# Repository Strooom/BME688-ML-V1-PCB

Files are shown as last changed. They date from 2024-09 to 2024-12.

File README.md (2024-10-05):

# BME688 Machine Learning PCB



KiCAD design files for the BME688 Machine Learning PCB.

## Front render
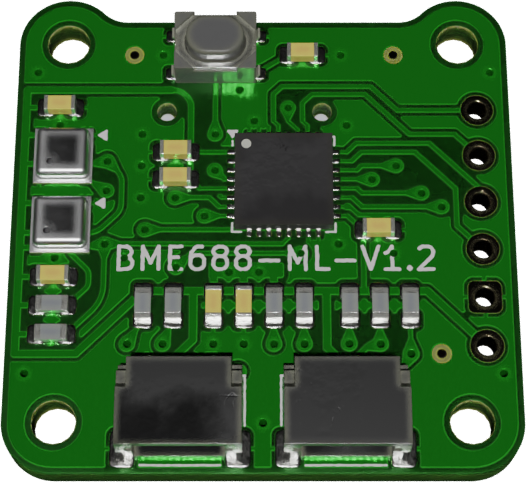
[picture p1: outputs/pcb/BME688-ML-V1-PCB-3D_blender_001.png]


## Back render
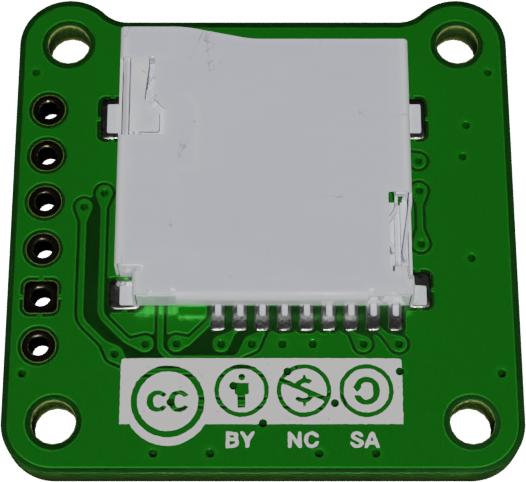
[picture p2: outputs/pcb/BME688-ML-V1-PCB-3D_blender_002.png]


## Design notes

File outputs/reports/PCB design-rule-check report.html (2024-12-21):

Logo

| DRC report for BME688-ML-V1-PCB
| PCB: BME688-ML-V1-PCB Revision: None Date: 2024-12-21T13:22:17+0000 KiCad Version: 8.0.6 | Errors: 0 Warnings: 0 Total: 0

Generated by KiBot (https://github.com/INTI-CMNB/KiBot/) v1.8.2

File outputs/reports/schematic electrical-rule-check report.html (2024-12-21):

Logo

| ERC report for BME688-ML-V1-PCB
| Schematic: BME688-ML-V1-PCB Revision: V1 Date: 2024-12-21T13:22:16+0000 KiCad Version: 8.0.6 | Errors: 0 Warnings: 2 Total: 2

Sheet / (BME688-ML-V1-PCB.kicad_sch)

Type | Description | Details
lib_symbol_issues | Symbol 'Qwiic connector' has been modified in library '1projectLibrary' | @(0.7493 mm, 1.4732 mm): Symbol CONN1 [Qwiic connector]
lib_symbol_issues | Symbol 'Qwiic connector' has been modified in library '1projectLibrary' | @(1.0033 mm, 1.4732 mm): Symbol CONN2 [Qwiic connector]

Generated by KiBot (https://github.com/INTI-CMNB/KiBot/) v1.8.2

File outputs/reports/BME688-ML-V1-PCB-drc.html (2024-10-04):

Logo

| DRC report for BME688-ML-V1-PCB
| PCB: BME688-ML-V1-PCB Revision: Date: 2024-10-04T11:17:32+0000 KiCad Version: 8.0.4 | Errors: 0 Warnings: 0 Total: 0

Generated by KiBot (https://github.com/INTI-CMNB/KiBot/) v1.8.1

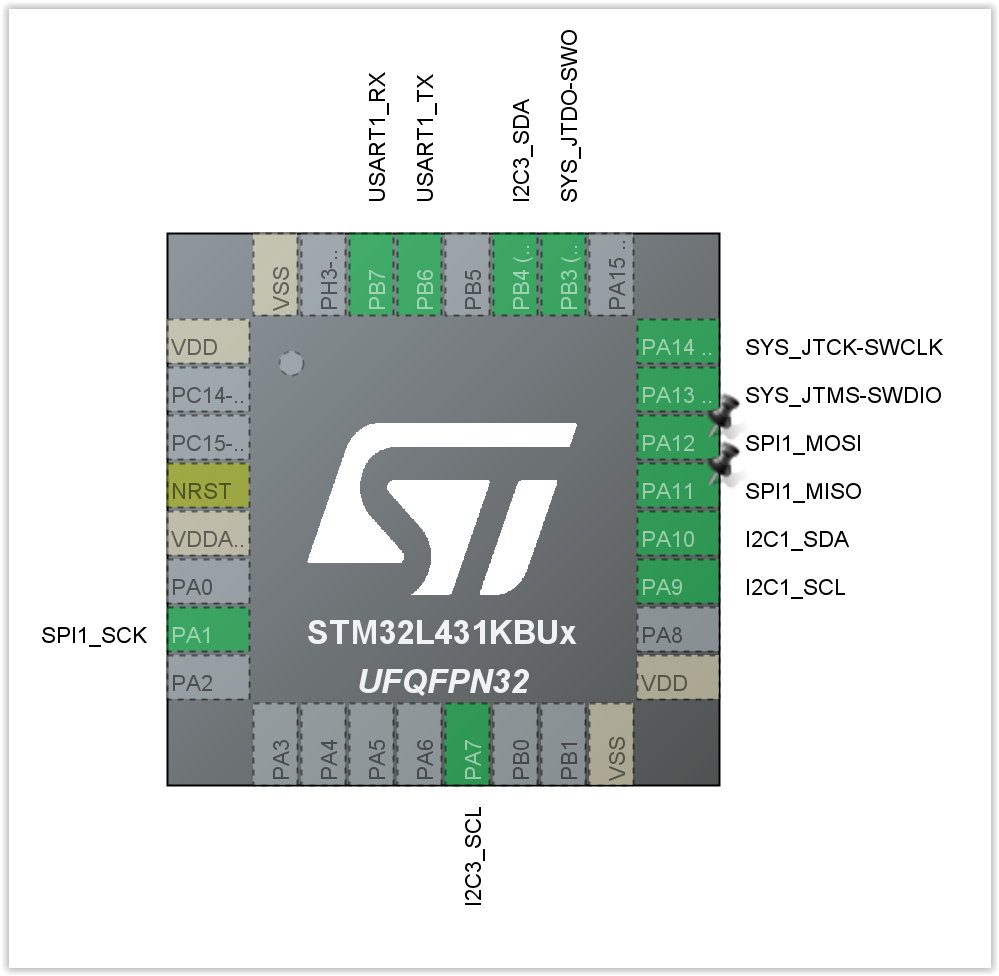
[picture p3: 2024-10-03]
inputs/other/Pinout STM32.PNG

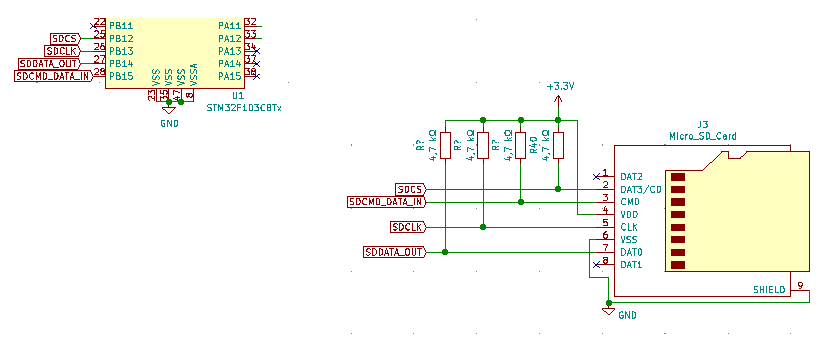
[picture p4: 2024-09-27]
inputs/other/kwdvX.png

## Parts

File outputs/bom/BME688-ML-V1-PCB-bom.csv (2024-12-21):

Row | Description | Part | References | Value | Footprint | Quantity Per PCB | Status | Datasheet | GPN | manufacturerName | manufacturerPartNumber | digikeyPartNumber | mouserPartNumber | octopartUrl | MPN | manufacturer | supplier1Name | supplier1PartNumber | supplier1PartURL | supplier2Name | supplier2PartNumber | supplier2PartURL | remark
1 | 4u7 | C | C4 C5 | C0603C475K8PAC7411 | C_0603_nominal | 2 |  | https://www.mouser.be/datasheet/2/447/KEM_C1006_X5R_SMD-3316465.pdf | GPC0603475 | Yageo - Kemet | C0603C475K8PAC7411 | 399-C0603C475K8PAC7411CT-ND | 80-C0603C475K8PACLR | https://octopart.com/c0603c475k8pac7411-kemet-75146718?r= | C0603C475K8PAC7411
2 | 100nF | C | C1 C2 C3 C6 C7 C8 | KGM15AR71C104KT | C_0603_nominal | 6 |  | https://www.mouser.be/datasheet/2/40/KGM_X7R-3223212.pdf | GPC0603104 | KYOCERA AVX | KGM15AR71C104KT | 478-KGM15AR71C104KTCT-ND | 581-KGM15AR71C104KT | https://octopart.com/kgm15ar71c104kt-avx-136559929?r=sp | KGM15AR71C104KT
3 | micro-SD card slot | microSdCard | CONN3 | MSD-1-A | MSD-1-A | 1 |  | https://www.mouser.be/datasheet/2/670/msd_1_a-3367597.pdf |  | CUI Devices | MSD-1-A |  | 179-MSD-1-A | https://octopart.com/msd-1-a-same+sky-145369555?r=sp | MSD-1-A
4 | Qwiic | Qwiic connector | CONN1 CONN2 | SM04B-SRSS-TB | JST_SH_SM04B-SRSS-TB_1x04-1MP_P1.00mm_Horizontal | 2 |  | https://www.mouser.be/datasheet/2/813/eSH-2487316.pdf |  | Sparkfun - JST | SM04B-SRSS-TB(LF)(DN)(P) |  | 306-SM04BSRSSTBLFDNP | https://octopart.com/sm04b-srss-tb%28lf%29%28dn%29%28p%29-jst-154671066?r=sp | SM04B-SRSS-TB
5 | Debug-SWD | Conn_01x06_Socket | CONN5 | notApplicable | DebugConnector_1x06_P2.54mm | 1 |  | notApplicable |  | notApplicable | notApplicable | notApplicable | notApplicable | notApplicable
6 | 4K7 | R | R1 R2 R3 R4 R5 R6 R7 R8 R9 | CR0603-FX-4701ELF | R_0603_nominal | 9 |  | https://www.mouser.be/datasheet/2/54/cr-1858361.pdf | GPR06034K7 | Bourns | CR0603-FX-4701ELF | CR0603-FX-4701ELFCT-ND | 652-CR0603FX-4701ELF | https://octopart.com/cr0603-fx-4701elf-bourns-3867100?r=sp | CR0603-FX-4701ELF
7 | Application buttonswitch | Switch_434133025816 | SW1 | 434133025816 | Wurth-434133025816 | 1 |  | https://www.we-online.com/components/products/datasheet/434133025816.pdf |  | Wurth Electronics | 434133025816 | 732-13663-1-ND | 710-434133025816 | https://octopart.com/434133025816-wurth+elektronik-99472342?r=sp | 434133025816
8 | Air Quality Sensors MEMS gas, humidity, pressure and temperature sensor | BME688 | U2 U3 | BME688 | BME688 | 2 |  | https://ae-bst.resource.bosch.com/media/_tech/media/datasheets/BST-BME680-DS001.pdf |  | Bosch Sensortec | BME688 | 828-BME688CT-ND | 262-BME688 | https://octopart.com/bme688-bosch+tools-116090840?r=sp | BME688 | Bosch Sensortec | Mouser | 262-BME680 | https://www.mouser.be/ProductDetail/Bosch-Sensortec/BME680?qs=v271MhAjFHjo0yA%2FC4OnDQ%3D%3D | Digi-Key | 828-1077-1-ND | https://www.digikey.be/nl/products/detail/bosch-sensortec/BME680/7401317
9 | STMicroelectronics Arm Cortex-M4 MCU, 128-256KB flash, 64KB RAM, 80 MHz, 1.71-3.6V, 26 GPIO, UFQFPN32 | STM32L431K | U1 | STM32L431KBU6TR | QFN-32-1EP_5x5mm_P0.5mm_EP3.45x3.45mm | 1 |  | https://www.st.com/resource/en/datasheet/stm32l431kb.pdf |  | ST | STM32L431KBU6TR | 497-18831-1-ND | 511-STM32L431KBU6TR | https://octopart.com/stm32l431kbu6tr-stmicroelectronics-89206856?r=sp | STM32L431KBU6TR
Project info:
Schematic: | BME688-ML-V1-PCB
Variant: | default
Revision: | V1
Date: | 2024-09-18
KiCad Version: | 8.0.6+1
Statistics:
Component Groups: | 9
Component Count: | 25
Fitted Components: | 25
Number of PCBs: | 1
Total Components: | 25

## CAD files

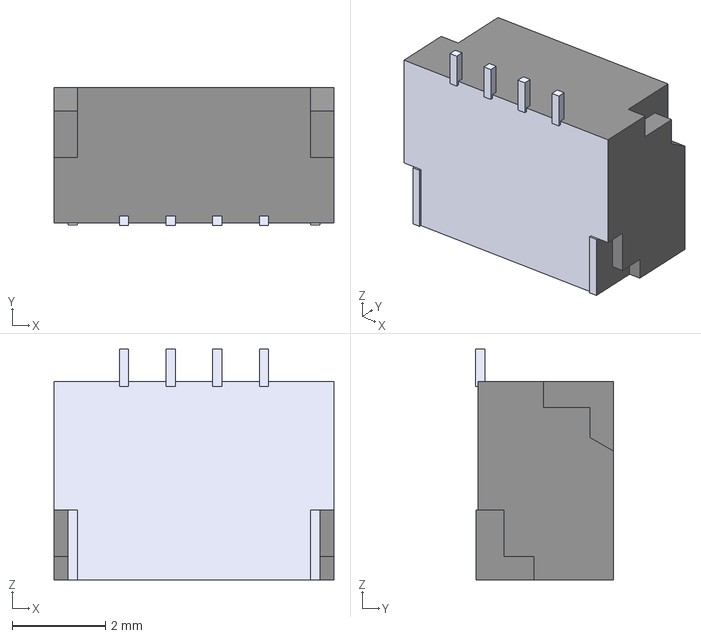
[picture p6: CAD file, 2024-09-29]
inputs/3dmodels/SPARKFUN_QWIIC_RIGHT_ANGLE.step
6.00 x 2.96 x 4.95 mm

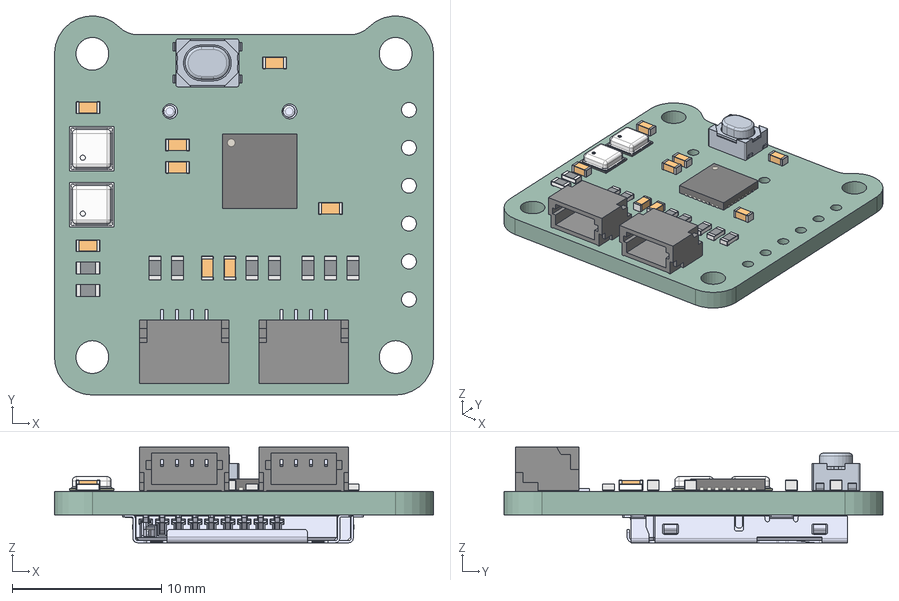
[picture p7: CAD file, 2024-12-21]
outputs/pcb/BME688-ML-V1-PCB-3D.step
25.4 x 25.4 x 6.40 mm
SPARKFUN_QWIIC_RIGHT_ANGLE_X x 2
QFN-32-1EP_5x5mm_Pitch0.5mm
Assem1
BME680 x 2
CUI_DEVICES_MSD-1-A
kibot_do8knjwf_PCB

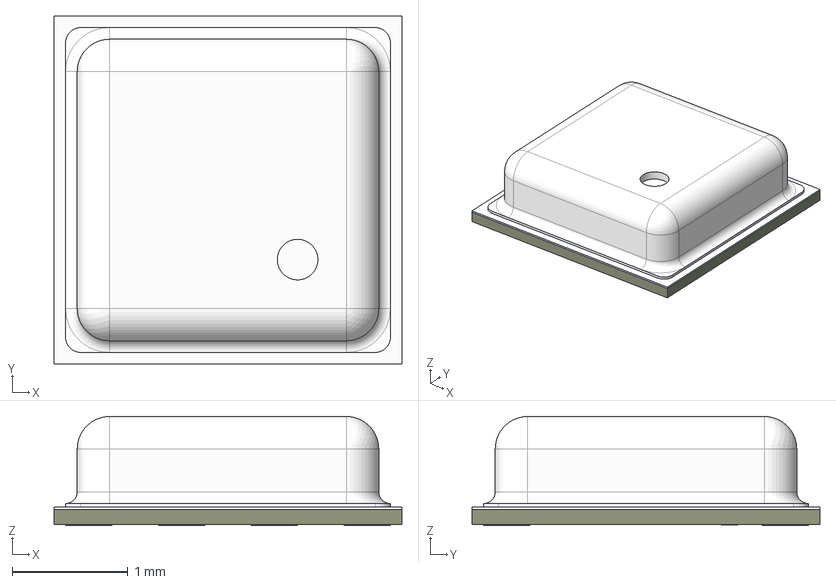
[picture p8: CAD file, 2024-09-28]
inputs/3dmodels/BME688.step
3.00 x 3.00 x 0.94 mm
pads
pcb
lid

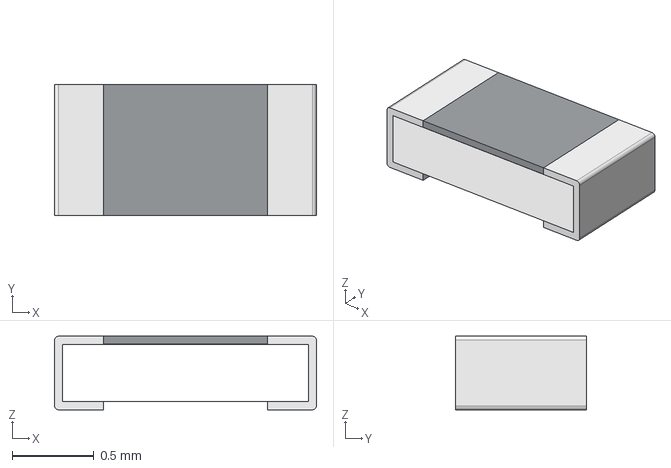
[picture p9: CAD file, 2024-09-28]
inputs/3dmodels/R0603.step
1.60 x 0.8 x 0.45 mm

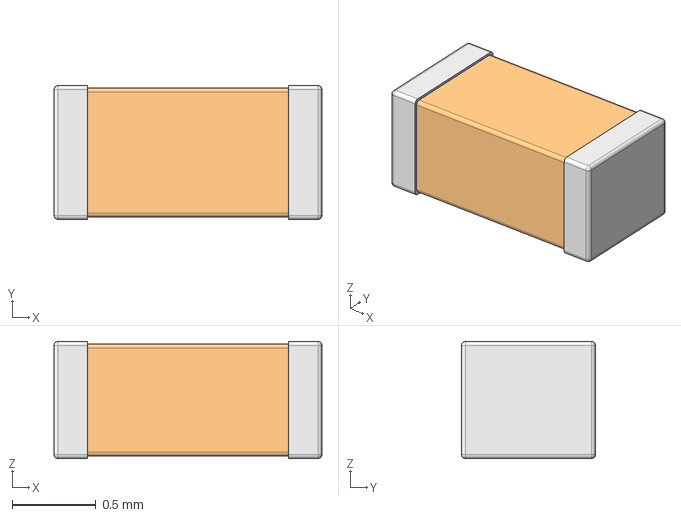
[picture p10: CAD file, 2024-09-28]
inputs/3dmodels/C0603.step
1.60 x 0.8 x 0.7 mm

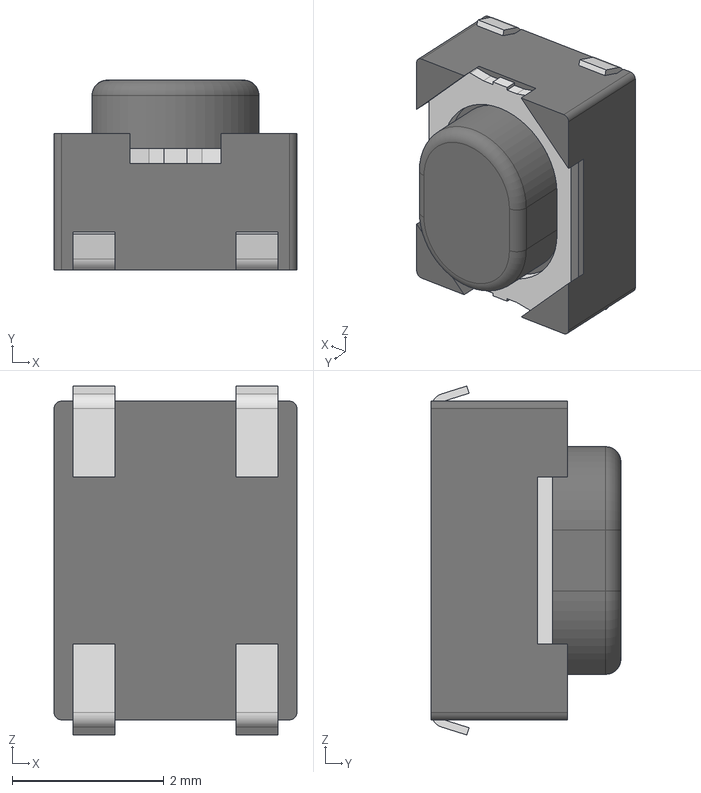
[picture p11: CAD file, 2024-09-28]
inputs/3dmodels/4341x30258x6.stp
3.20 x 2.50 x 4.60 mm
Frame
Cover
Stem
Terminal x 4

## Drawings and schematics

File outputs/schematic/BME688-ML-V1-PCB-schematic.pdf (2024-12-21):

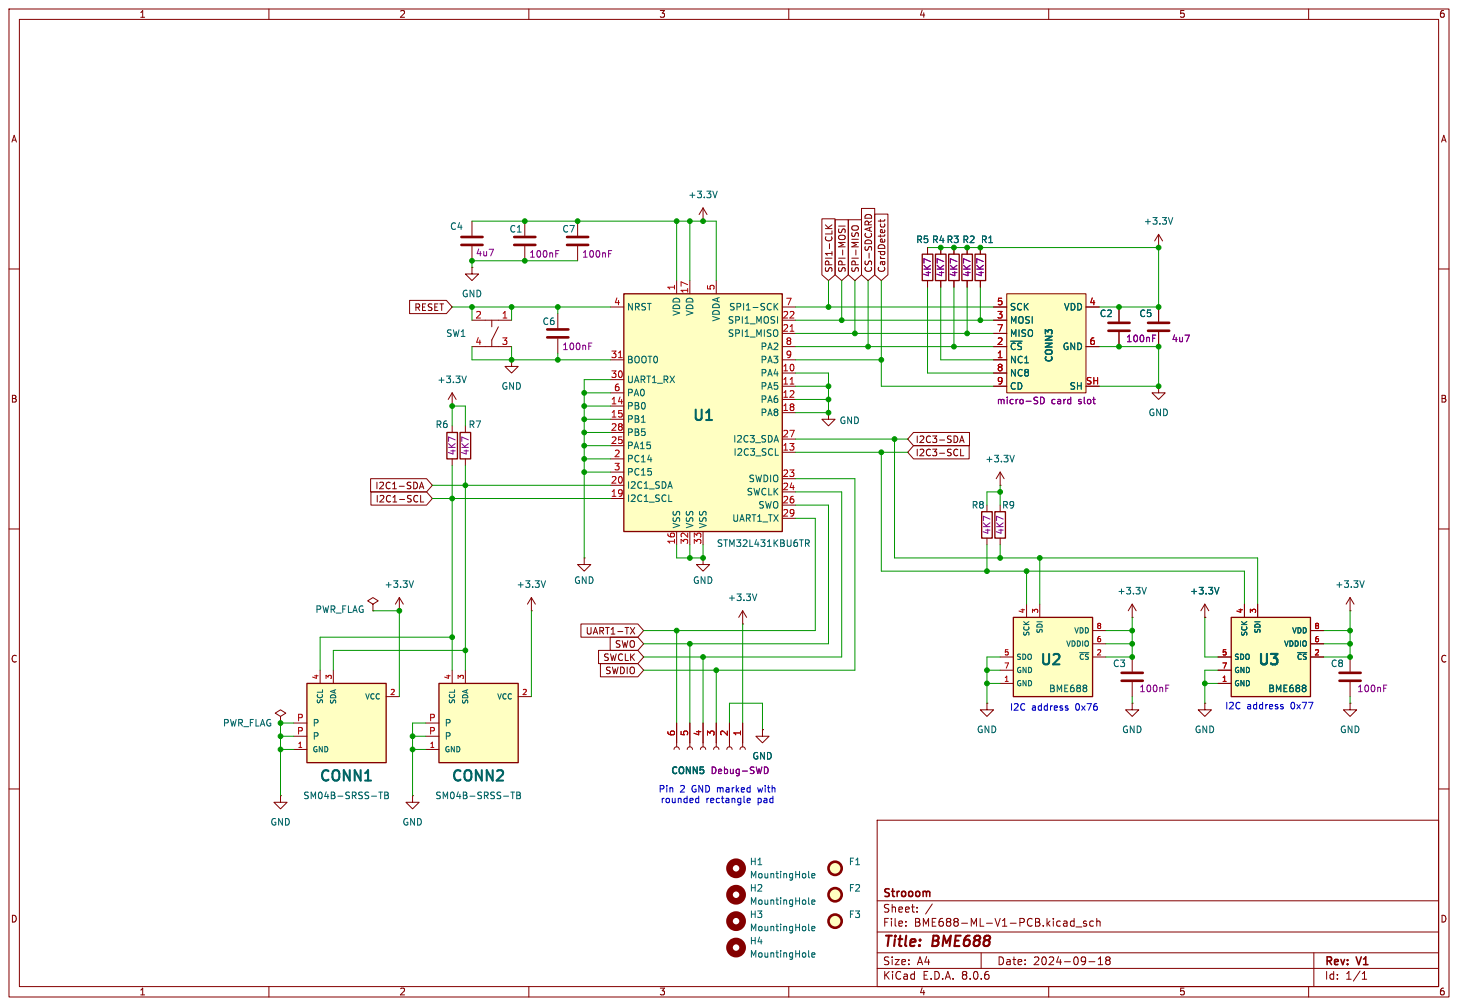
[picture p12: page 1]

4 SDO 5 VDDIO 6 GND 7 VDD 8 CONN3 micro-SD card slot NC1 1 ~{CS} 2 MOSI 3 VDD 4 SCK 5 GND 6 MISO 7 NC8 8 CD 9 SH SH

4 SDO 5 VDDIO 6 GND 7 VDD 8 U2

4 SDO 5 VDDIO 6 GND 7 VDD 8 U3

I2C address 0x77 Pin 2 GND marked with

File: BME688-ML-V1-PCB.kicad_sch Sheet: / Strooom

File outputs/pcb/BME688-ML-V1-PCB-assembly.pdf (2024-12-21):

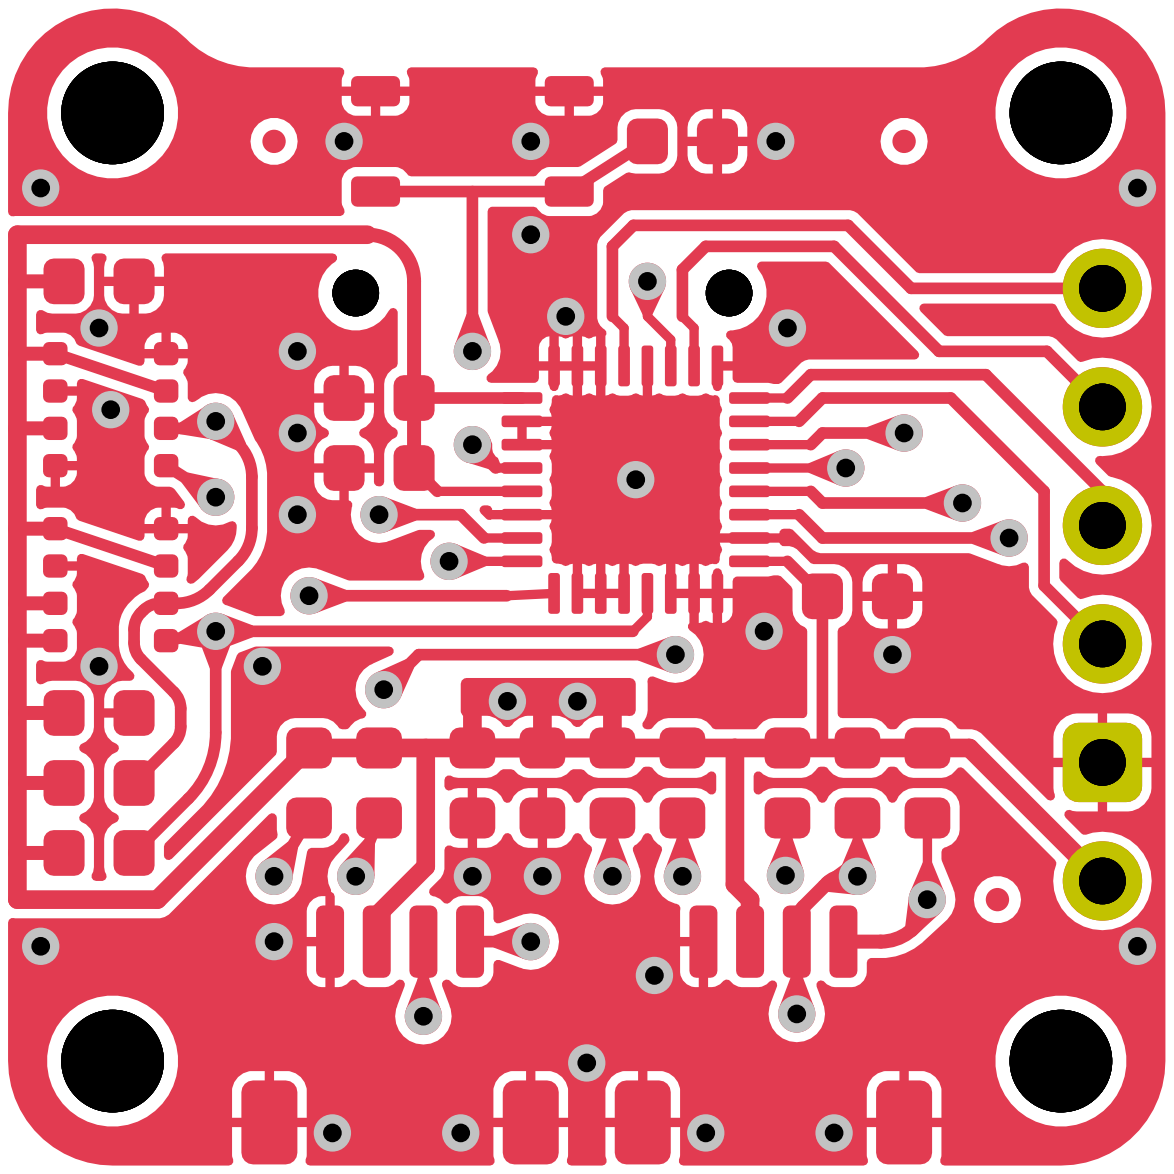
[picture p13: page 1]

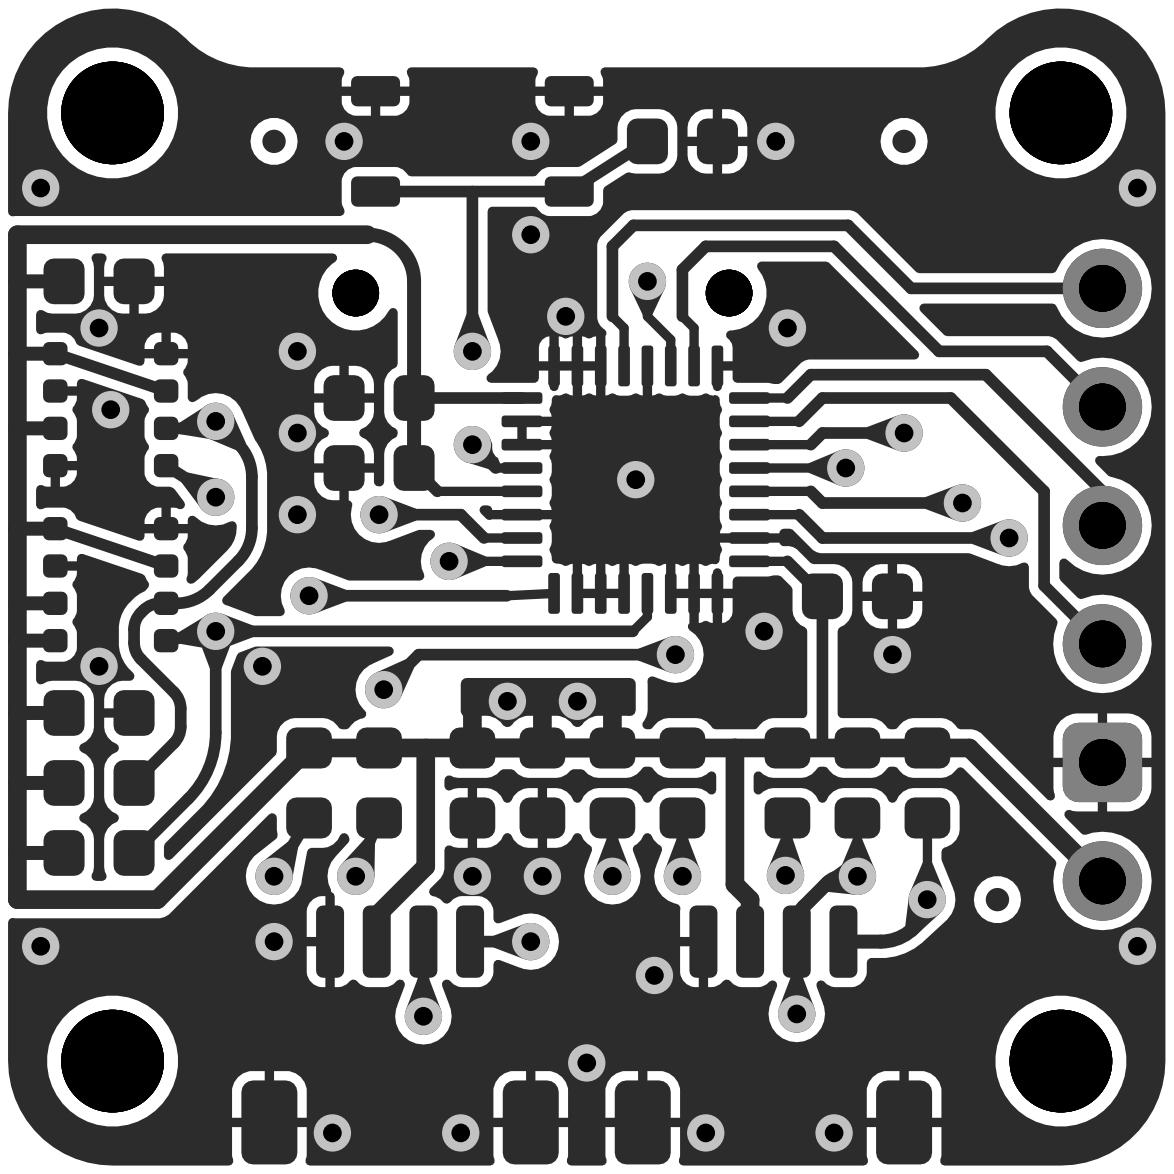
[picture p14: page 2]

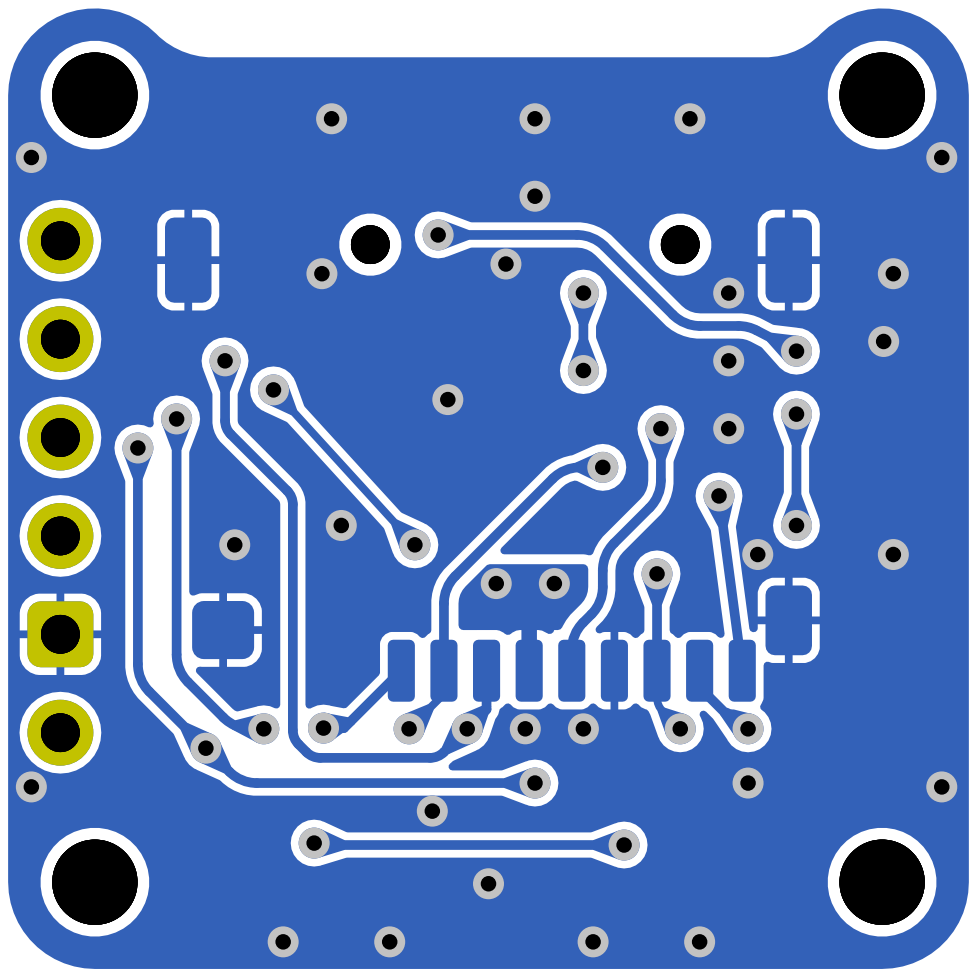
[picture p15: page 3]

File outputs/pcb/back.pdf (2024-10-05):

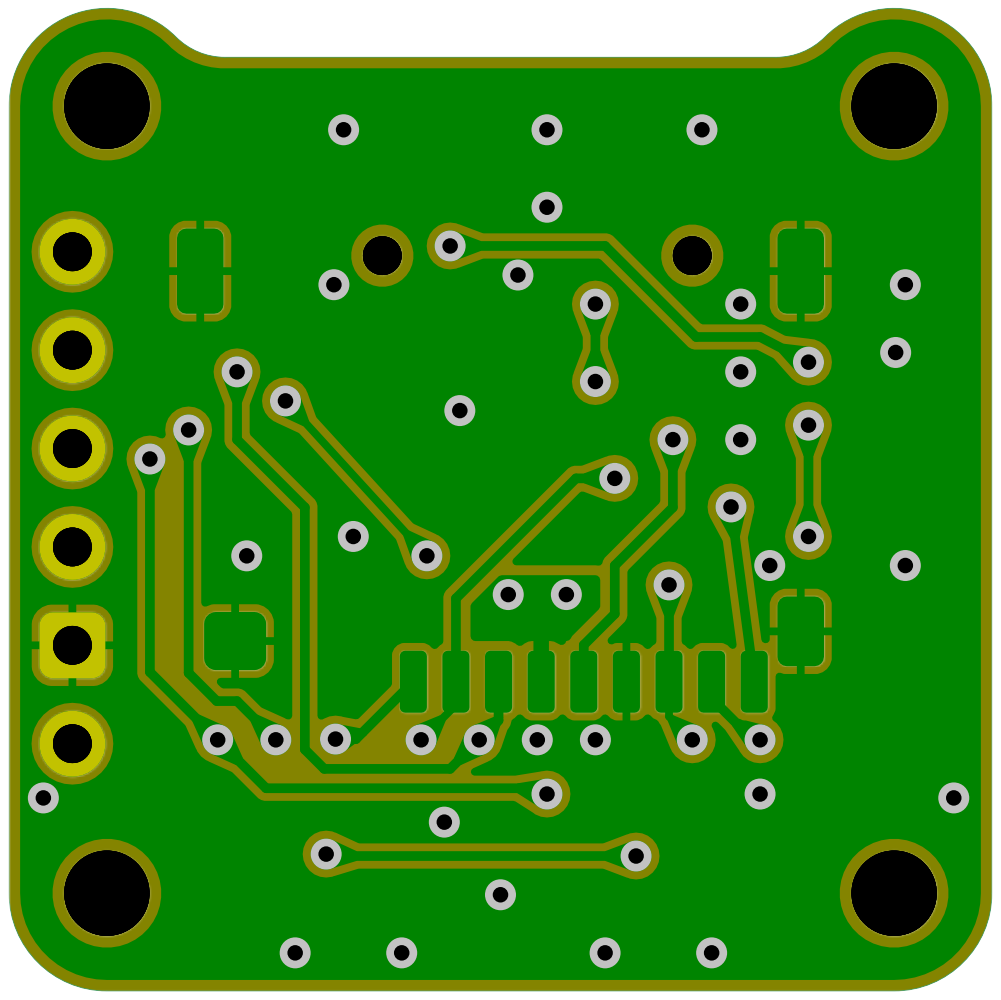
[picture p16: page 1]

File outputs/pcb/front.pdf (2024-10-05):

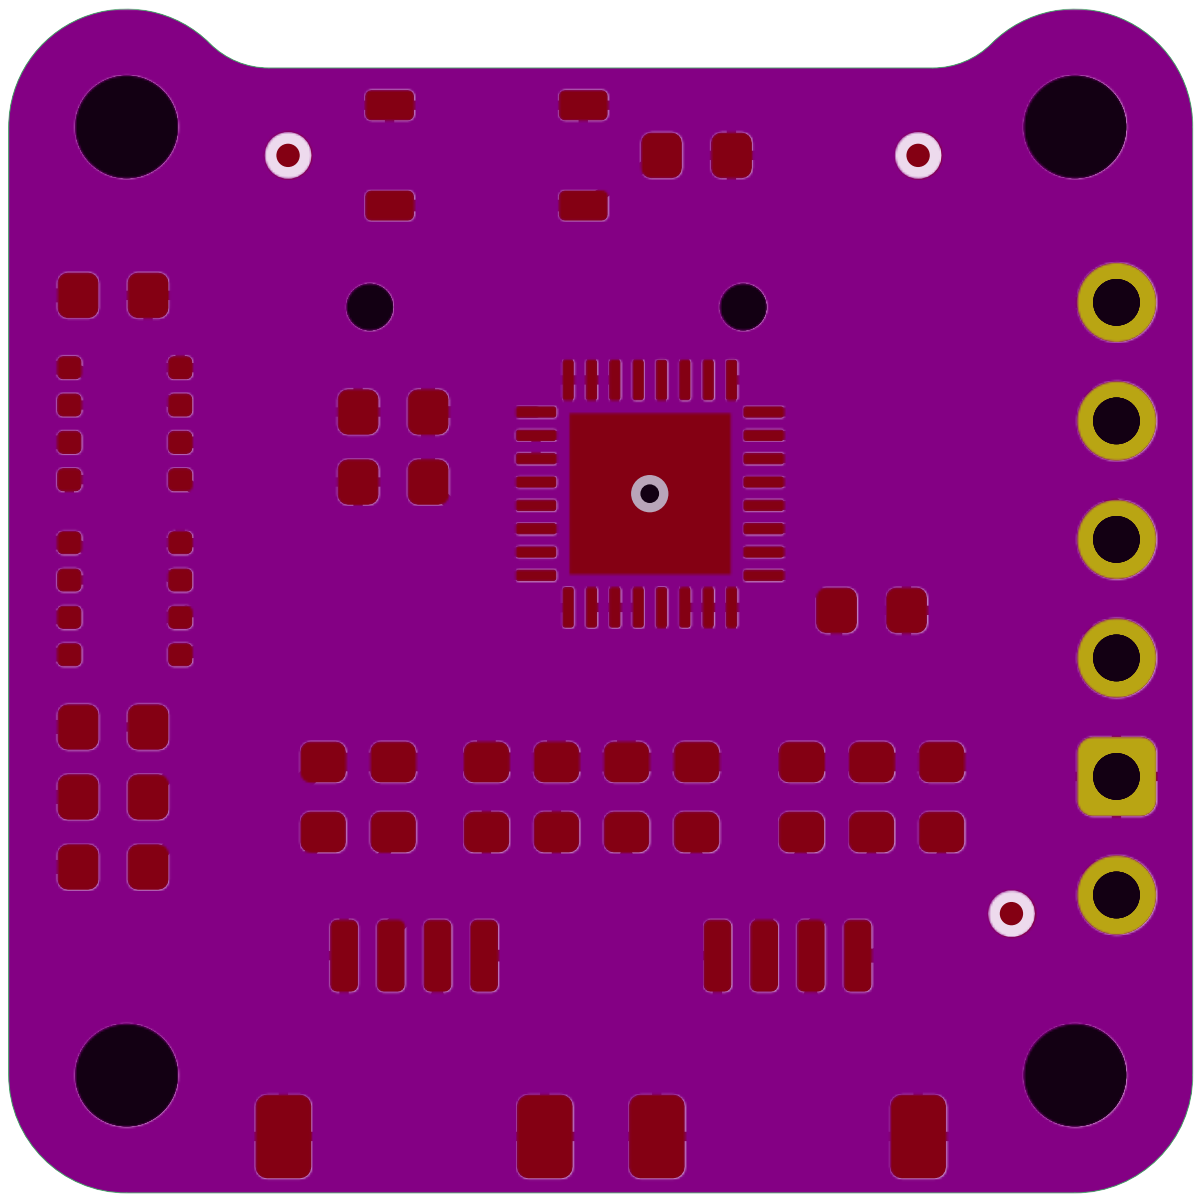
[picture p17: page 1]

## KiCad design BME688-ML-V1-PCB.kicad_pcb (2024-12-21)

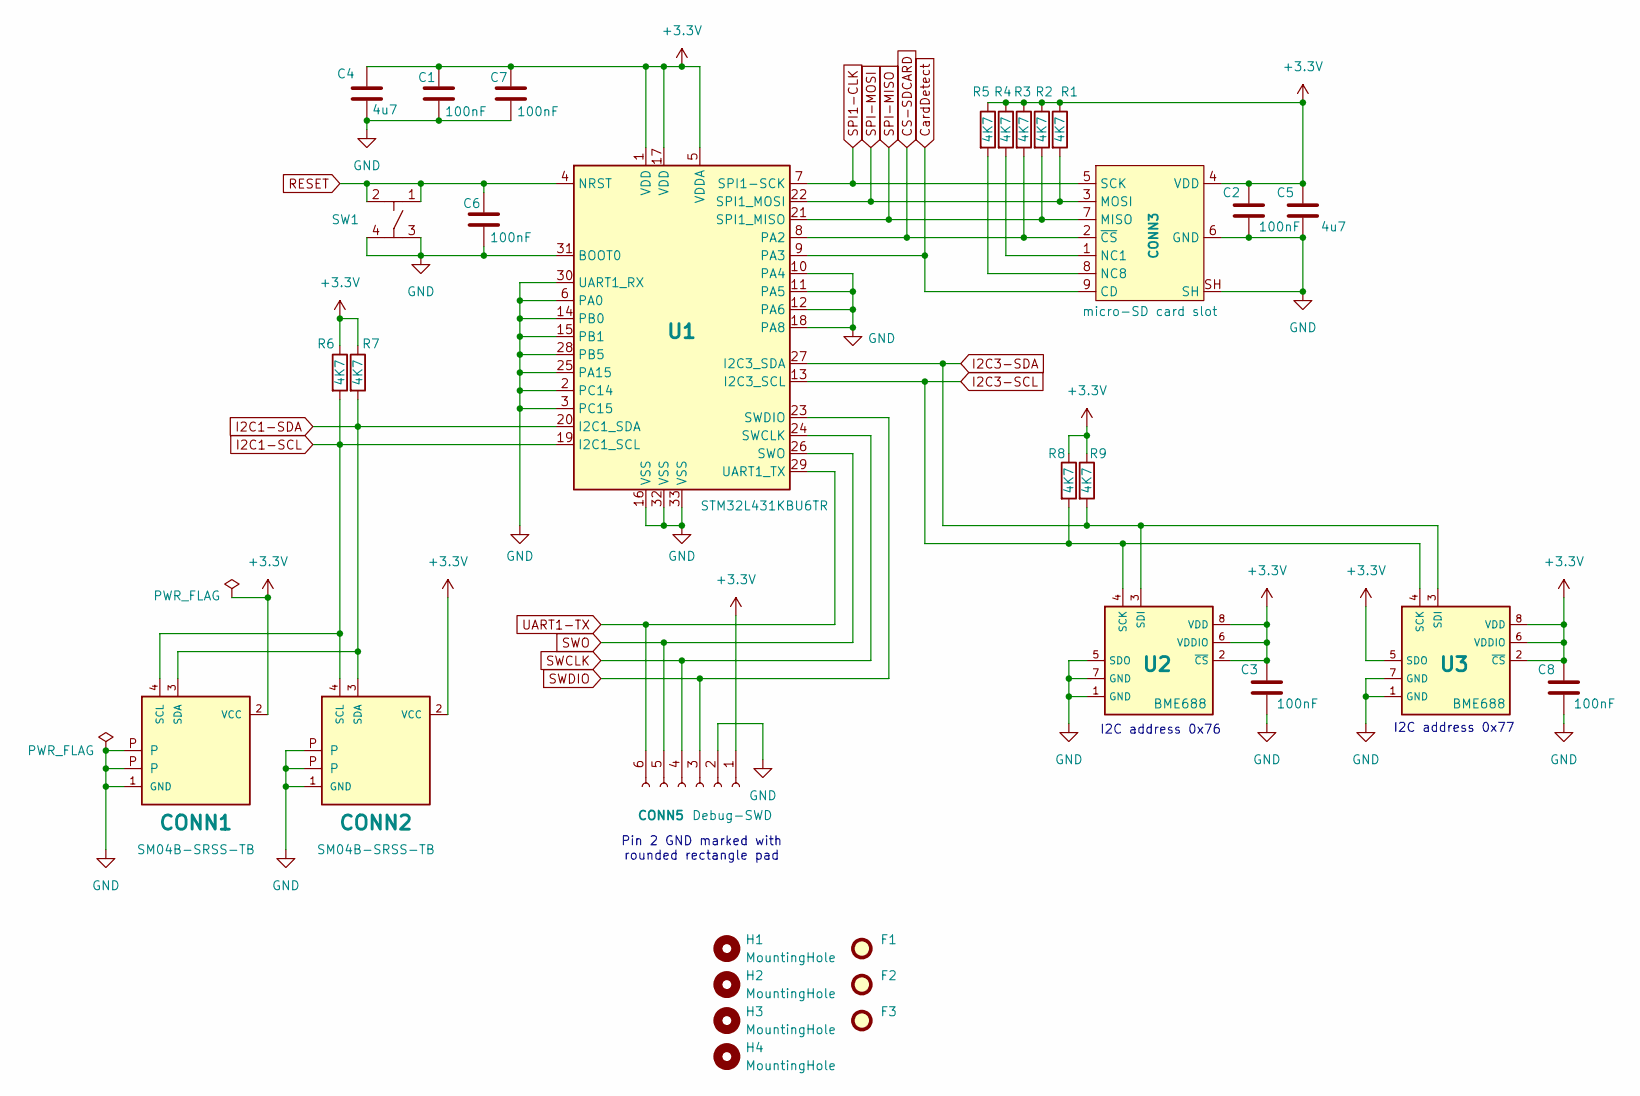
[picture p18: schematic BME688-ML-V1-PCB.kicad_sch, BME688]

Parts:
C1, C2, C3, C6, C7, C8: KGM15AR71C104KT; C_0603_nominal; manufacturerPartNumber KGM15AR71C104KT; digikeyPartNumber 478-KGM15AR71C104KTCT-ND
C4, C5: C0603C475K8PAC7411; C_0603_nominal; manufacturerPartNumber C0603C475K8PAC7411; digikeyPartNumber 399-C0603C475K8PAC7411CT-ND
CONN1, CONN2: SM04B-SRSS-TB; JST_SH_SM04B-SRSS-TB_1x04-1MP_P1.00mm_Horizontal; mouserPartNumber 306-SM04BSRSSTBLFDNP
CONN3: MSD-1-A; mouserPartNumber 179-MSD-1-A
CONN5: notApplicable; DebugConnector_1x06_P2.54mm; manufacturerPartNumber notApplicable; digikeyPartNumber notApplicable
F1, F2, F3: Fiducial; Fiducial_0.5mm_Mask1mm; manufacturerPartNumber notApplicable; digikeyPartNumber notApplicable
H1, H2, H3, H4: MountingHole; MountingHole_2.2mm_M2; manufacturerPartNumber notApplicable; digikeyPartNumber notApplicable
R1, R2, R3, R4, R5, R6, R7, R8, R9: CR0603-FX-4701ELF; R_0603_nominal; manufacturerPartNumber CR0603-FX-4701ELF; mouserPartNumber 652-CR0603FX-4701ELF
SW1: 434133025816; Wurth-434133025816; manufacturerPartNumber 434133025816; digikeyPartNumber 732-13663-1-ND
U1: STM32L431KBU6TR; QFN-32-1EP_5x5mm_P0.5mm_EP3.45x3.45mm; manufacturerPartNumber STM32L431KBU6TR; digikeyPartNumber 497-18831-1-ND
U2, U3: BME688; manufacturerPartNumber BME688; digikeyPartNumber 828-BME688CT-ND

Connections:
+3.3V: C1.1, C2.1, C3.1, C4.1, C5.1, C7.1, C8.1, CONN1.2 (VCC), CONN2.2 (VCC), CONN3.4 (VDD), CONN5.1, R1.1, R2.1, R3.1, R4.1, R5.1, R6.1, R7.1, R8.1, R9.1, U1.1 (VDD), U1.5 (VDDA), U1.17 (VDD), U2.2 (~CS), U2.6 (VDDIO), U2.8 (VDD), U3.2 (~CS), U3.5 (SDO), U3.6 (VDDIO), U3.8 (VDD)
CS-SDCARD: CONN3.2 (~CS), R3.2, U1.8 (PA2)
CardDetect: CONN3.9 (CD), U1.9 (PA3)
GND: C1.2, C2.2, C3.2, C4.2, C5.2, C6.2, C7.2, C8.2, CONN1.1 (GND), CONN1.P, CONN2.1 (GND), CONN2.P, CONN3.6 (GND), CONN3.SH, CONN5.2, SW1.3, SW1.4, U1.2 (PC14), U1.3 (PC15), U1.6 (PA0), U1.10 (PA4), U1.11 (PA5), U1.12 (PA6), U1.14 (PB0), U1.15 (PB1), U1.16 (VSS), U1.18 (PA8), U1.25 (PA15), U1.28 (PB5), U1.30 (UART1_RX), U1.31 (BOOT0), U1.32 (VSS), U1.33 (VSS), U2.1 (GND), U2.5 (SDO), U2.7 (GND), U3.1 (GND), U3.7 (GND)
I2C1-SCL: CONN1.4 (SCL), CONN2.4 (SCL), R6.2, U1.19 (I2C1_SCL)
I2C1-SDA: CONN1.3 (SDA), CONN2.3 (SDA), R7.2, U1.20 (I2C1_SDA)
I2C3-SCL: R8.2, U1.13 (I2C3_SCL), U2.4 (SCK), U3.4 (SCK)
I2C3-SDA: R9.2, U1.27 (I2C3_SDA), U2.3 (SDI), U3.3 (SDI)
unnamed: CONN3.1 (NC1), R4.2
unnamed: CONN3.8 (NC8), R5.2
RESET: C6.1, SW1.1, SW1.2, U1.4 (NRST)
SPI1-CLK: CONN3.5 (SCK), U1.7 (SPI1-SCK)
SPI-MISO: CONN3.7 (MISO), R2.2, U1.21 (SPI1_MISO)
SPI-MOSI: CONN3.3 (MOSI), R1.2, U1.22 (SPI1_MOSI)
SWCLK: CONN5.4, U1.24 (SWCLK)
SWDIO: CONN5.3, U1.23 (SWDIO)
SWO: CONN5.5, U1.26 (SWO)
UART1-TX: CONN5.6, U1.29 (UART1_TX)

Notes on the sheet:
Pin 2 GND marked with rounded rectangle pad
I2C address 0x76
I2C address 0x77

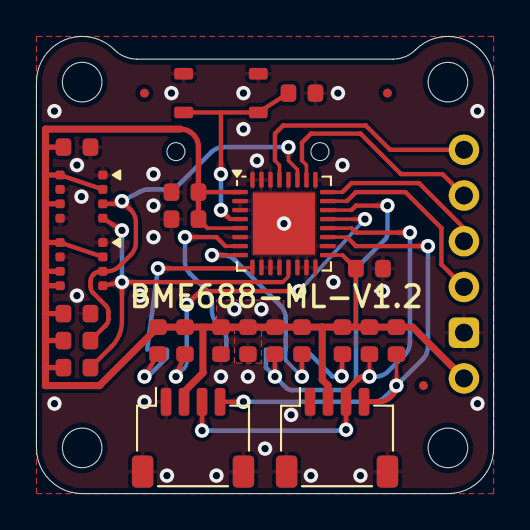
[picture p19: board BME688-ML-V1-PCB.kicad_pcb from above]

Board: 2 copper layers, 25.4 x 25.4 mm, 32 parts (1 on the bottom side), 18 nets.

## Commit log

2024-09-27 add workflow
    [BME688-ML-V1-PCB.kicad_pcb, BME688-ML-V1-PCB.kicad_sch, BME688.csv]
2024-09-28 reorganize folders
    [BME688-ML-V1-PCB.kicad_sch]
2024-09-28 remove dependency on global library
    [BME688-ML-V1-PCB.kicad_pcb, BME688-ML-V1-PCB.kicad_sch]
2024-09-28 fix 3dmodel for R0603 and C0603
    [BME688-ML-V1-PCB.kicad_pcb, C0603.step, R0603.step]
2024-09-28 commit CI artifacts to repository io attaching them to the workflow
2024-09-28 remove dependencies on global library
    [4341x30258x6.stp, BME688-ML-V1-PCB.kicad_pcb, BME688-ML-V1-PCB.kicad_sch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]
2024-09-29 Continuous Integration Build Artifacts
    [BME688-ML-V1-PCB-3D.step]
2024-09-29 add qwiic 3d model
    [BME688-ML-V1-PCB.kicad_pcb, SPARKFUN_QWIIC_RIGHT_ANGLE.step]
2024-09-29 fix both QWIIC connectors
    [BME688-ML-V1-PCB.kicad_pcb]
2024-09-29 remove pcb_print
2024-09-30 fix
    Tie BOOT0/PH3 to GND, as without the SW is not running stable..
    [BME688-ML-V1-PCB.kicad_pcb, BME688-ML-V1-PCB.kicad_sch]
2024-09-30 cleanup old files
    [BME688-ML-V1-PCB-3D.step]
2024-10-03 fix output options add new pin assignment for V1.2
2024-10-03 add workflow generated files
    [BME688-ML-V1-PCB-3D.step]
2024-10-04 Redesign for V1.2
    Moved BME688 onto its own I2C bus.
    Placed 2 BME688
    [BME688-ML-V1-PCB.kicad_pcb, BME688-ML-V1-PCB.kicad_sch]
2024-10-04 Add CC logo
    [BME688-ML-V1-PCB.kicad_pcb]
2024-10-04 remove board stackup
    [BME688-ML-V1-PCB.kicad_pcb]
2024-10-04 fix pcb_print
2024-10-04 remove old files improve scaling of pcb pdf
    [BME688-ML-V1-PCB-3D.step]
2024-10-04 experimenting with solder mask color
2024-10-04 small improvements in signal routing
    [BME688-ML-V1-PCB.kicad_pcb]
2024-10-04 move and add GND stitching vias
    [BME688-ML-V1-PCB.kicad_pcb]
2024-10-04 improve colors for pcb_print
2024-10-04 fix csv bom
2024-10-05 improve
    1. remove .csv from .gitignore so KiBOT can generate and add a csv.bom
    2. change view on render
2024-10-05 fix pcb_print color code
2024-10-05 fillet tracks for more beauty
    [BME688-ML-V1-PCB.kicad_pcb]
2024-12-21 updating BOM
    [BME688-ML-V1-PCB.kicad_pcb, BME688-ML-V1-PCB.kicad_sch]
